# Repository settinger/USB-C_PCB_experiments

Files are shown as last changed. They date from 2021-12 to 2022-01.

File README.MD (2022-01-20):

# USB-C PCB Experiments

This is part of an ongoing series of projects involving creative interpretations of the USB mechanical standards. You've probably seen [2.0mm thick PCBs that fit in USB ports](http://digistump.com/products/1), and maybe you've seen [0.6mm thick PCBs that fit in USB-Micro cables](https://twitter.com/DHammarskjold/status/1285291152602796032). So what about USB-C? The plastic tab inside a USB-C port is about 0.7mm thick. I think [bobricius](https://hackaday.io/bobricius) has had success using 0.8mm thick PCBs; 0.6mm thick PCBs are way too loose. I haven't found a fab that will do 0.7mm (or 28 mil) PCBs unless you special-order an entire panel.

So, what other ways are there to reach 0.7mm thickness? My original plan was to join an 0.1mm flex PCB and an 0.6mm FR4 PCB, but then I realized: you know what else is 0.6mm thick? The ATtiny84A BGA package. Granted, there are only contacts on one side of the PCB, but that shouldn't matter with the symmetric USB-C pinout, right? ...Right? (foreshadowing)

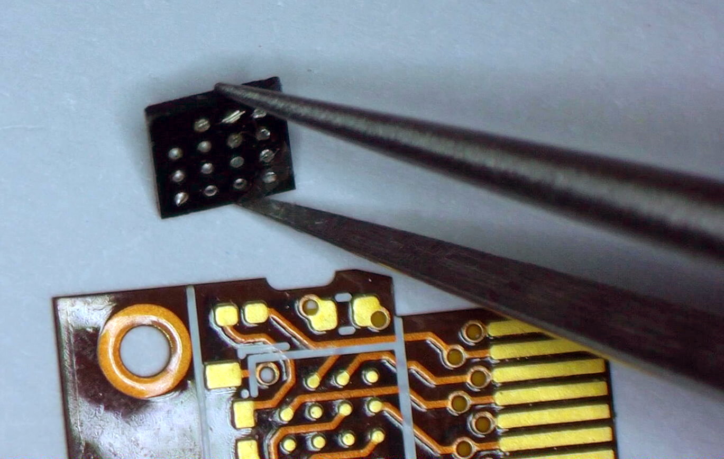
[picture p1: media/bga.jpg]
A close-up of the ATtiny84A in BGA package, next to a USB-C-shaped flex PCB


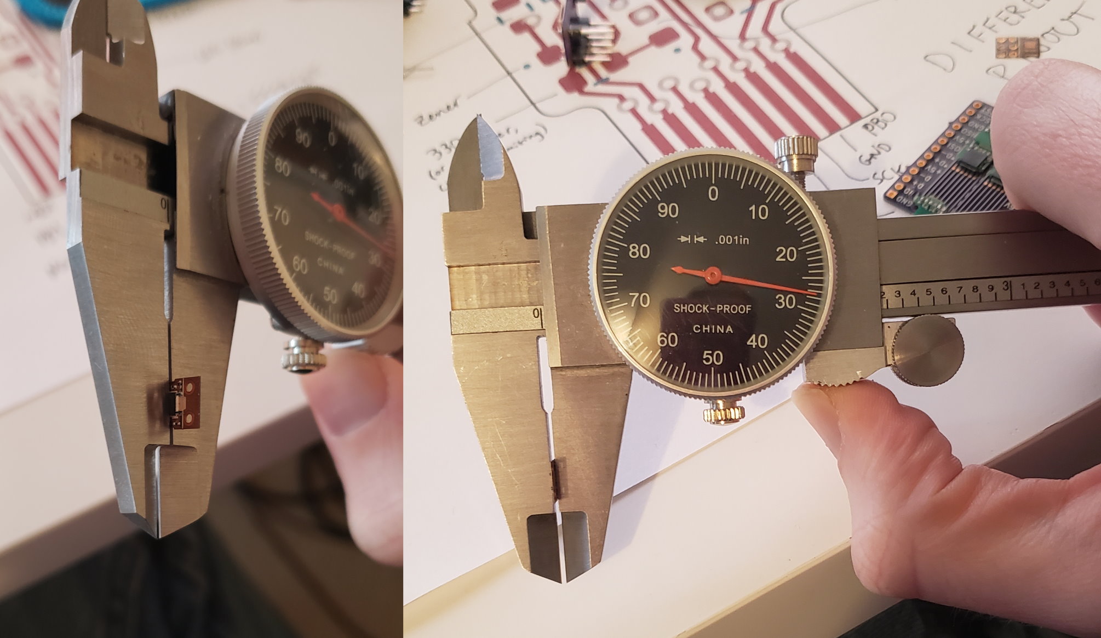
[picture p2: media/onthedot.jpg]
The BGA IC soldered onto the flex PCB, being measured by calipers that show 0.0275 inches (0.70 mm)


The 3mm-square ATtiny acts as a stiffener for the flex PCB, and it comes out to 0.7mm on the dot! I only have an imperial set of calipers as seen above. The dial shows 0.0275 inches, which is 0.6985 millimeters. ~~So this is looking pretty promising.~~ After [my initial tests](https://twitter.com/DHammarskjold/status/1476667605746270224), I am leaning toward a circuit sandwiched between two PCBs. The result is about 0.85mm thick with OSH Park flex PCBs, so I may need to locate another vendor.

What would you do with an ATtiny that lives inside your USB-C cable? I have a few ideas for demonstrations at the moment.

## Demo 1: RGB LED that can't be programmed over USB

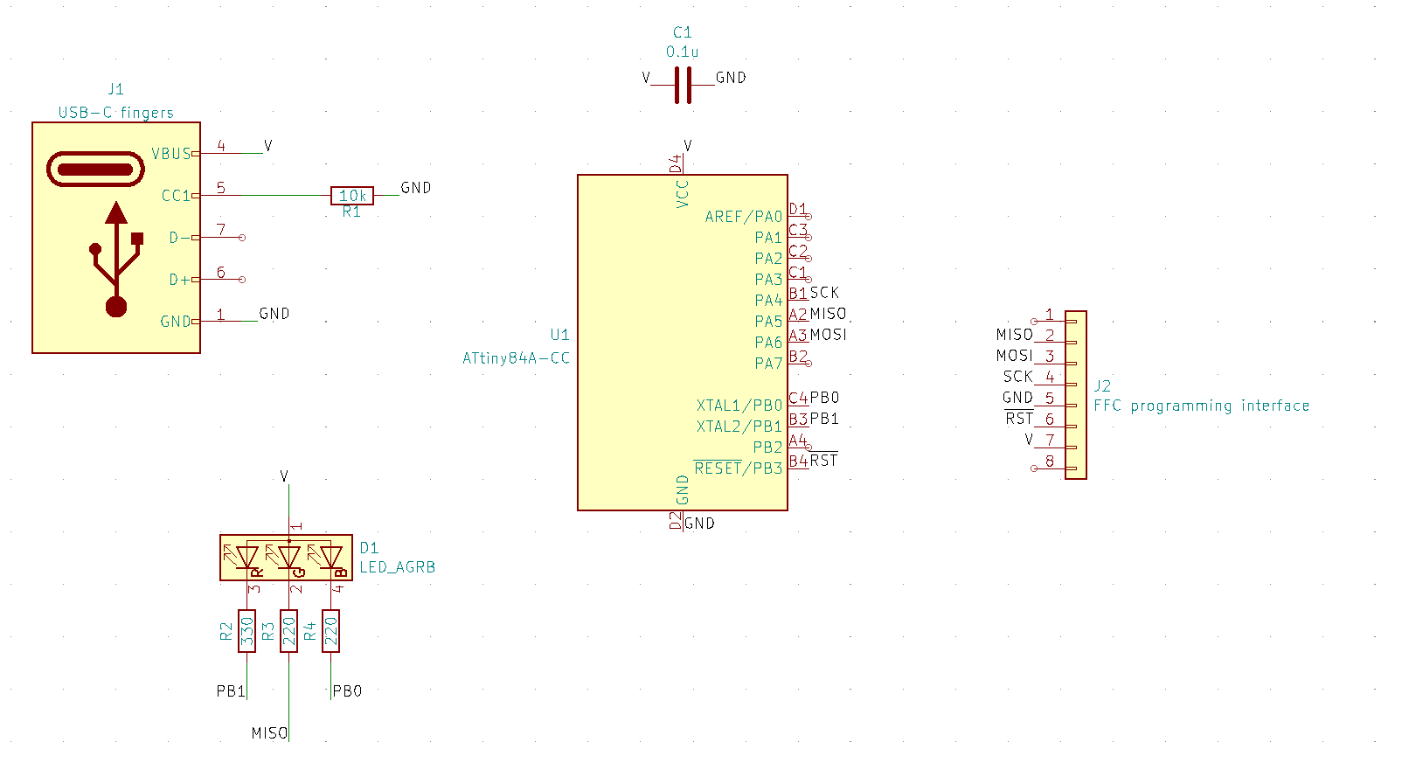
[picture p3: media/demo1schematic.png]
Schematic of revision 1 of the RGB LED USB-C PCB


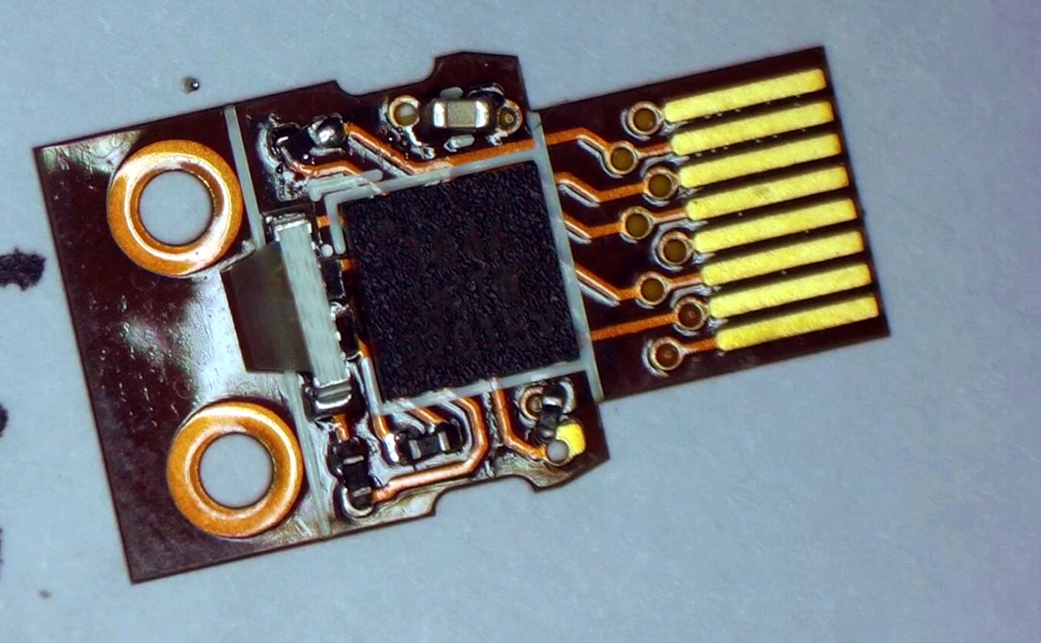
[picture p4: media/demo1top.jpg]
Top-down view of the assembled revision 1 PCB


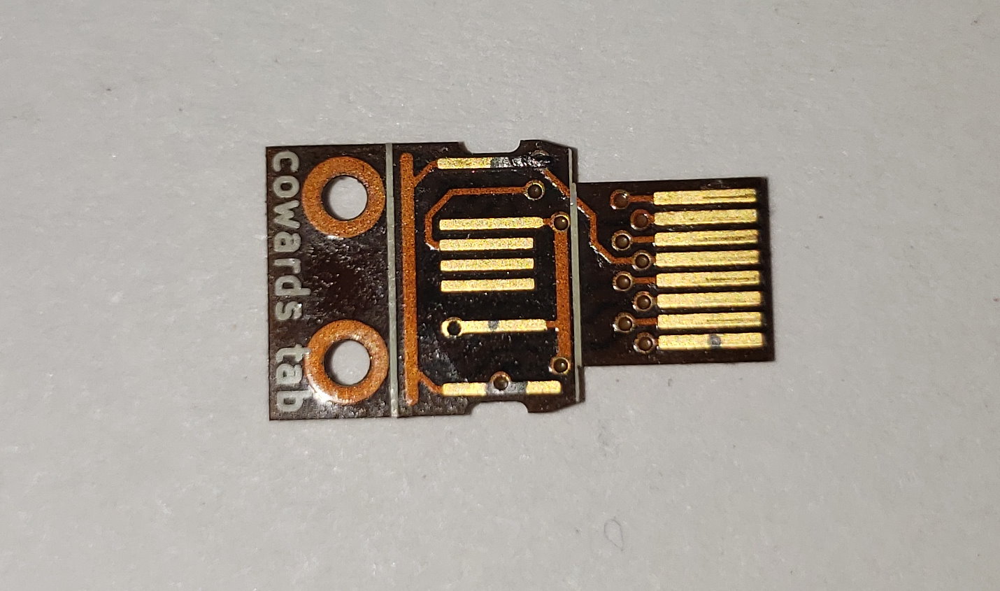
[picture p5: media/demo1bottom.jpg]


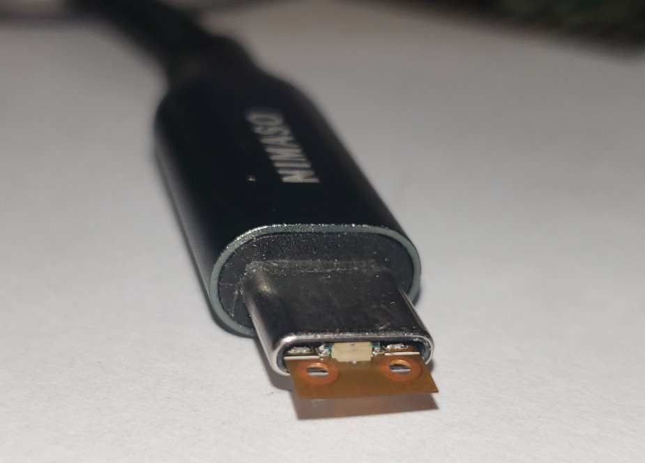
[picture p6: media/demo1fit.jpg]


There are two revisions of this design; the schematics are in the repo as `rgb_no_bootloader.kicad_sch` and `rgb_no_bootloader_r2.kicad_sch`. Revision 1 is the one that I have assembled and ready to work with, it's also the one I would like some code help with! My current code is in the in the code folder as `demo_1_revision_1`; it is saved as an Arduino .ino file but it should work fine with AVR-GCC without any changes.

This demo is as simple as possible: the microcontroller controlls an RGB LED that juuuust barely pokes out of the USB-C cable plug. It has to be programmed using that 8-pin FFC connector, and then the FFC connector has to be snipped off in order to use the dang thing. Right now I have one fully-soldered version of revision 1, ~~but I haven't cut the FFC connector yet because I would like some help improving the code.~~

Demo 1 Revision 2 is necessary because, on revision 1, the RGB LED is *not* connected to the Fast-PWM-enabled pins on the microcontroller. As a result I have to use [binary code modulation](http://www.batsocks.co.uk/readme/art_bcm_3.htm) to achieve any sort of brightness control. It's working alright, [as shown here](https://twitter.com/DHammarskjold/status/1475741148522049536), ~~but I'm not confident enough with the code to chop off the programming connector yet.~~

When I finally removed the connector, I documented it [in this Twitter thread](https://twitter.com/DHammarskjold/status/1476667605746270224). I got excited and tried putting it in a powered USB cable while the top side was exposed. Unsurprisingly, this caused some shorts and some damage! I soldered in a new RGB LED and applied conformal coating. The conformal coating helped for a little while, but got scraped away pretty quickly. This suggests to me that any future designs will need to be sandwiched between *two* PCBs.

As you can see, there is a large tab sticking out so I can grab and remove the PCB from the cable. However, out of spite for, uh, myself, I have labelled it the "cowards' tab." Past me was encouraging present me to remove that tab and make the board impossible to remove, thereby turning a useful cable into a cute little art piece for all eternity.

## Demo 2: ~~R~~GB LED that *can* be programmed over USB

It would be nice to use the USB data lines to program the microcontroller! I didn't attempt this for the first revision because I wanted to keep the board as uncluttered and simple as possible. It will result in a denser board that may need more careful soldering, but it should be possible! Well, *mostly* possible. I didn't find a way to route red green and blue at the same time, so I've omitted red from the design.

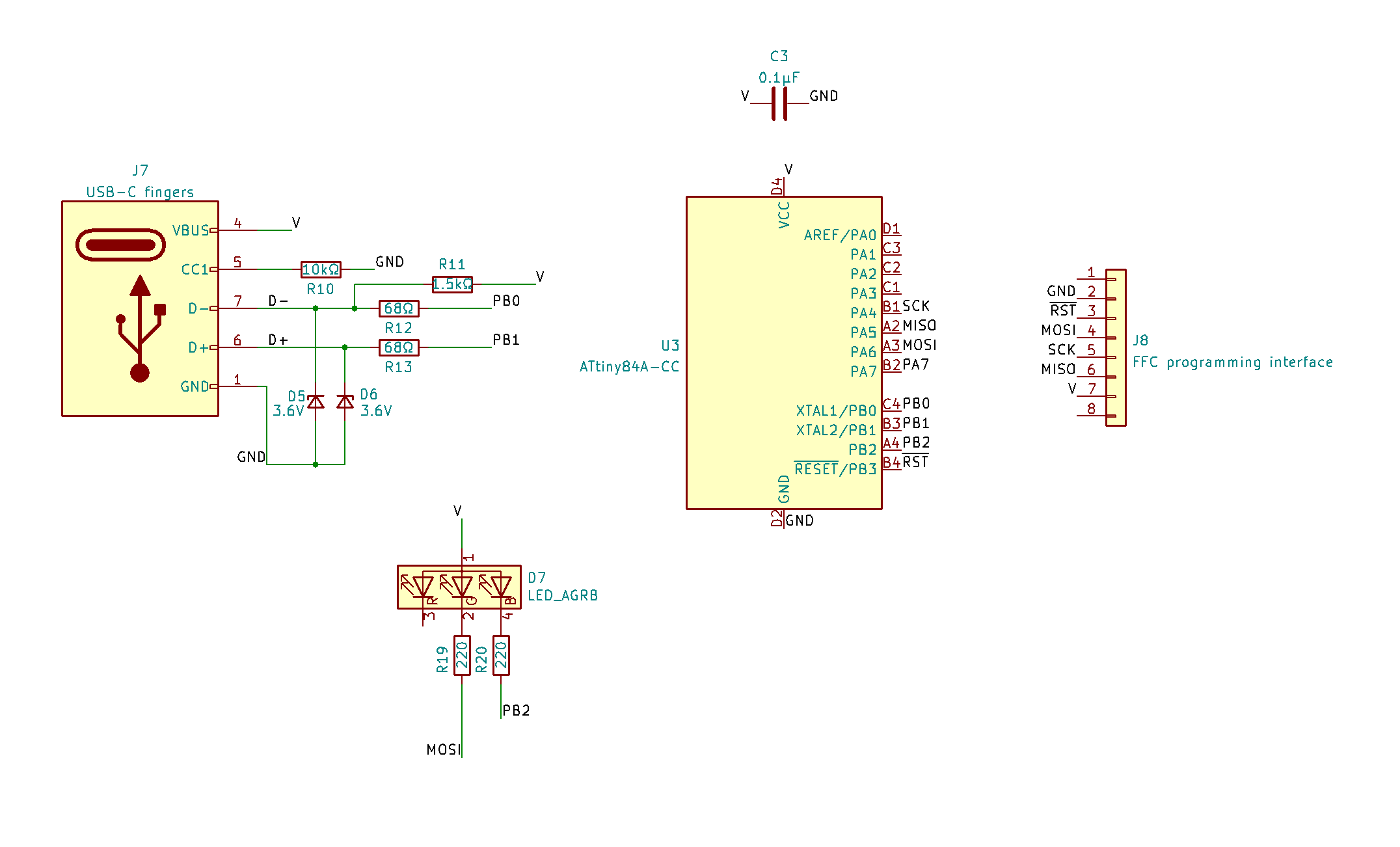
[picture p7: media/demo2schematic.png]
Schematic of the programmable RGB LED USB-C PCB


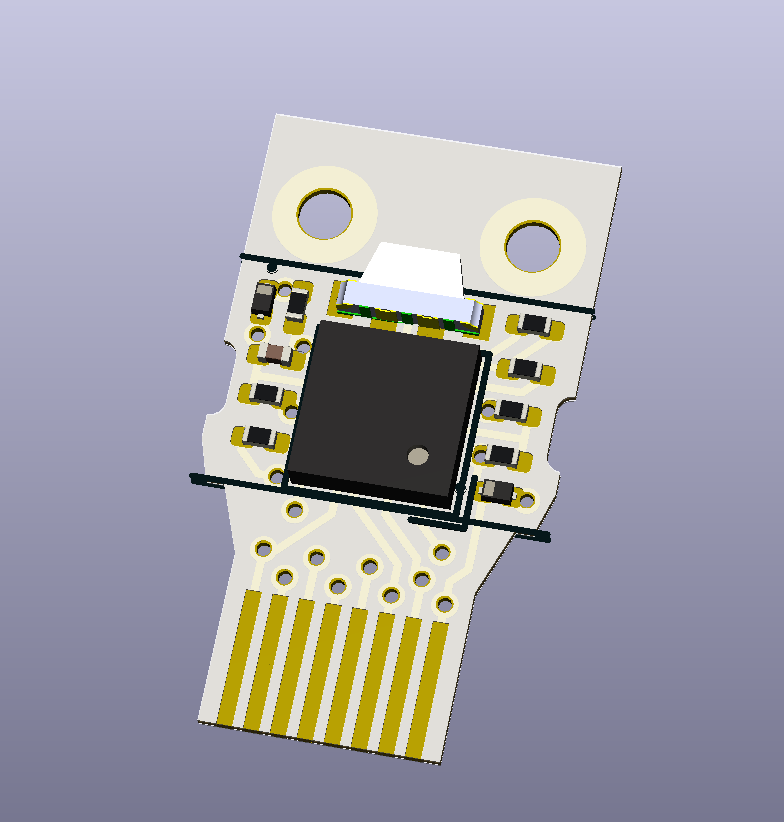
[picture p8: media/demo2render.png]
KiCad 3D render of the programmable RGB LED USB-C PCB


As I understand it, I need to add at least five extra components: a pullup for the D- line, small resistors on the D- and D+ lines, and zener diodes as level shifters. This is the low-complexity approach used on the Digispark and its derivatives. I have not attempted to make this board yet. Also, look at the 3d render above; doesn't it look like an owl? I love it.

There is an interesting issue, however. In the USB-C standard, the D+/D- lines are only connected on one side of the plug! It assumes that the USB-C port has D+/D- connectors on both sides, so the plug orientation should not matter. But our USB-C port only has D+/D- connectors on one side. We've reintroduced the classic USB behavior of having to flip the device over 3 times before it works!

## Demo 3: Basically a Digispark but smaller

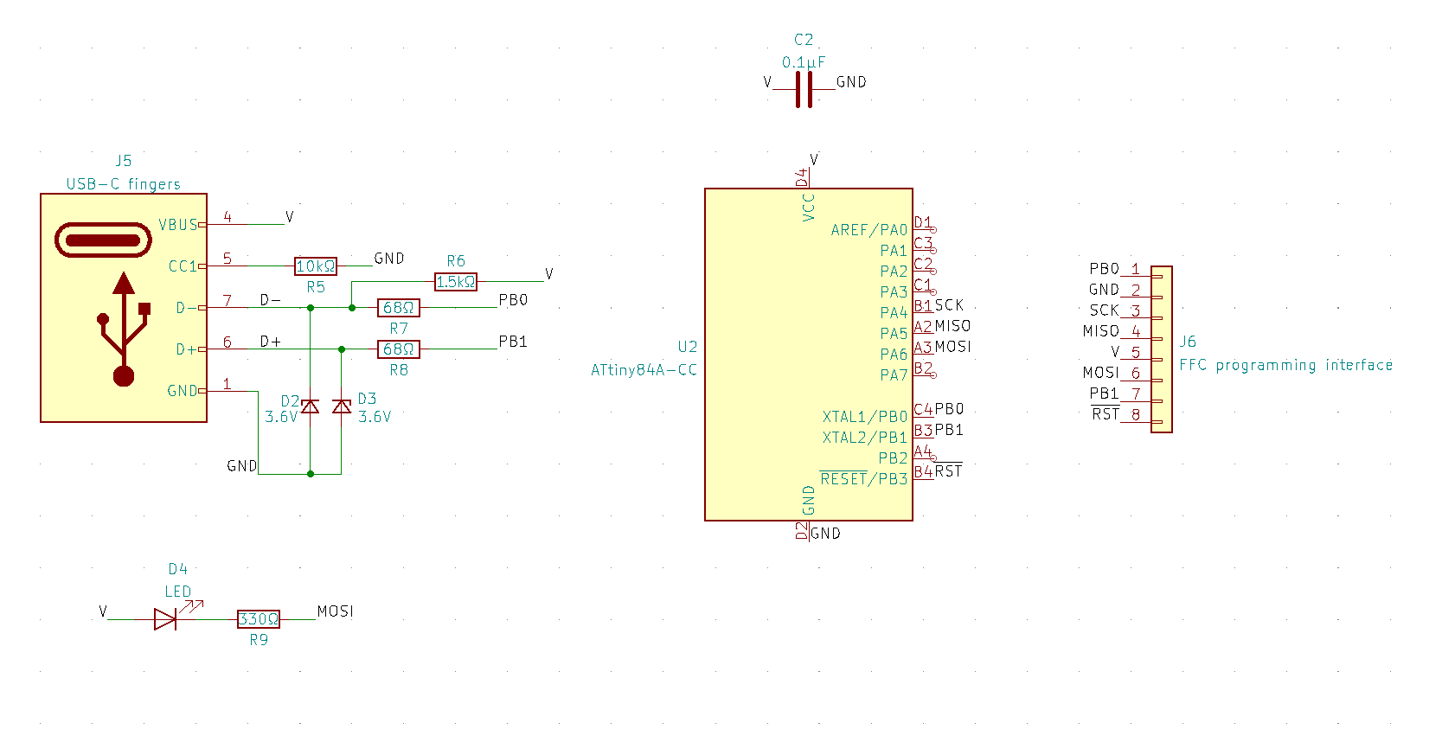
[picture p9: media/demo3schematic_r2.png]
Schematic of the miniature Digispark PCB


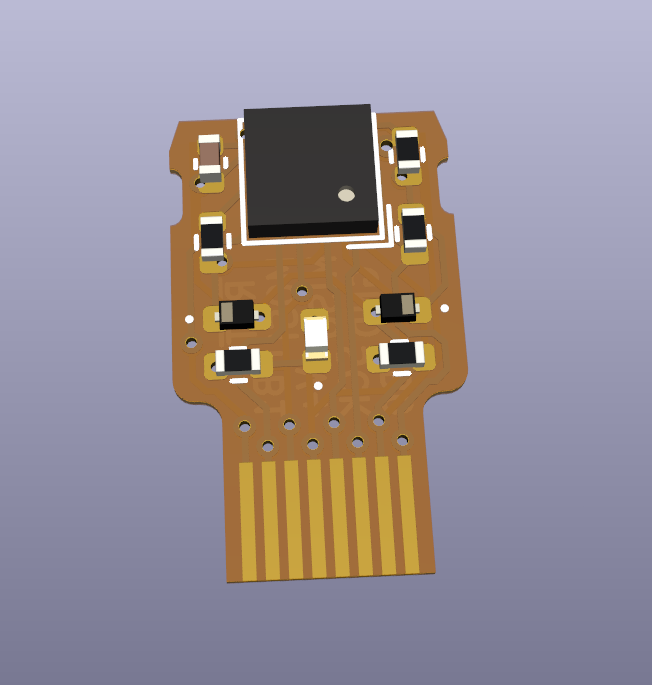
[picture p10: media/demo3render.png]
KiCad 3D render of the miniature Digispark PCB


In this version, the FFC portion is meant to stay attached! And all the components are 0402-sized with generous spacing so I can worry less when soldering. As a result it can be used in a slightly more "normal" fashion—still operable by sticking it inside a USB-C cable, but now there's a breakout of sorts.

## Demo 4: "Coulda used a 555"

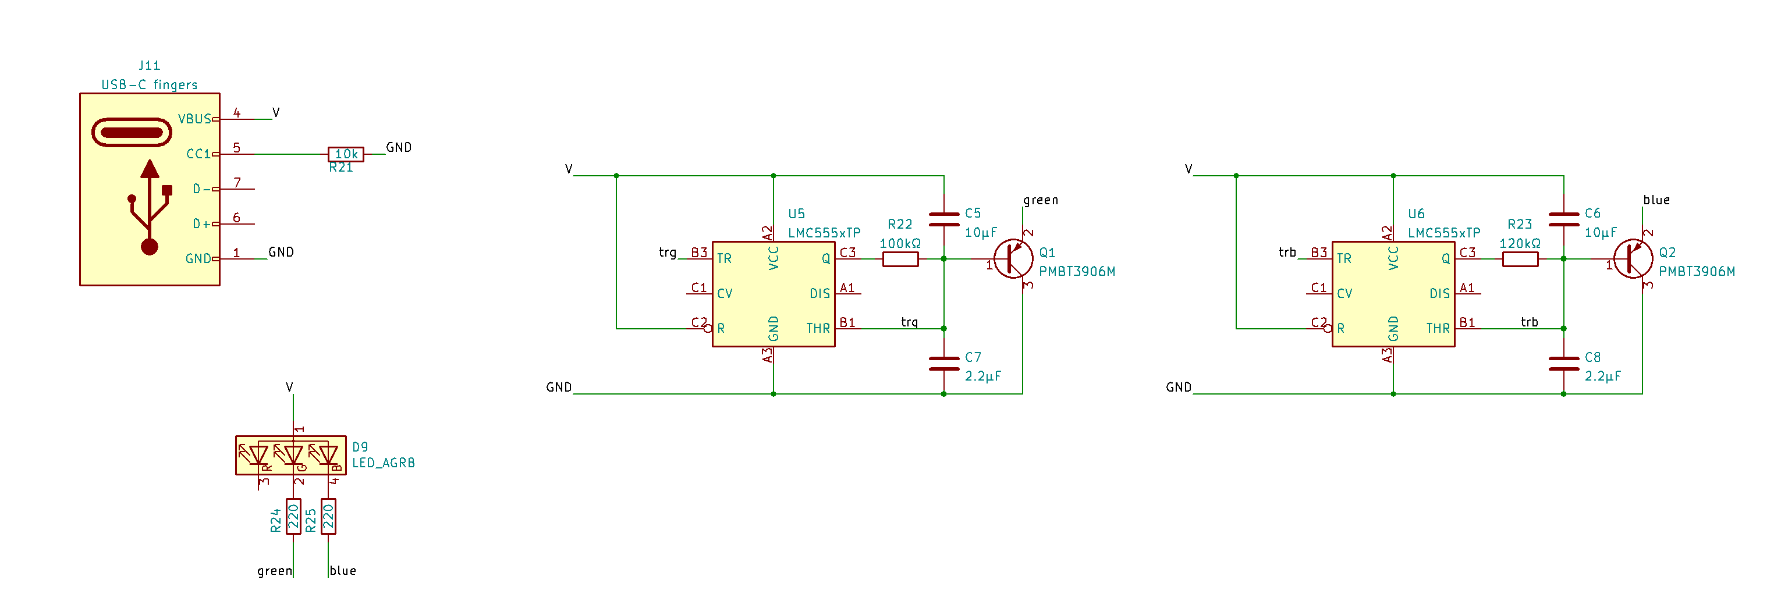
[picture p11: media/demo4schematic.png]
Schematic of the USB-C PCB using BGA 555 timers instead of a microcontroller


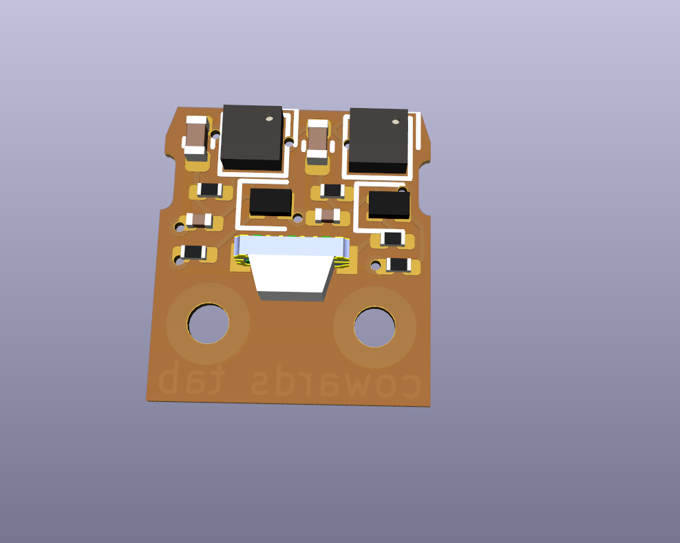
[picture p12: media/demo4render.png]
KiCad 3D render of the USB-C PCB using BGA 555 timers instead of a microcontroller


On the Hackaday websites, "Coulda used a 555" is shorthand for grumpy commenters who criticize designs that they consider inelegant, for example, using a microcontroller where a 555 would suffice. In the past I've poked fun at this notion by, among other things, using *three* microcontrollers where a 555 would suffice, and using a 555 Schmitt Trigger where a single SPST button would suffice. As luck would have it, there is a BGA 555 IC that is just shy of 0.6mm tall! I've had to pair it with a 10μF capacitor that is a bit taller, but it's a fun idea to explore later.

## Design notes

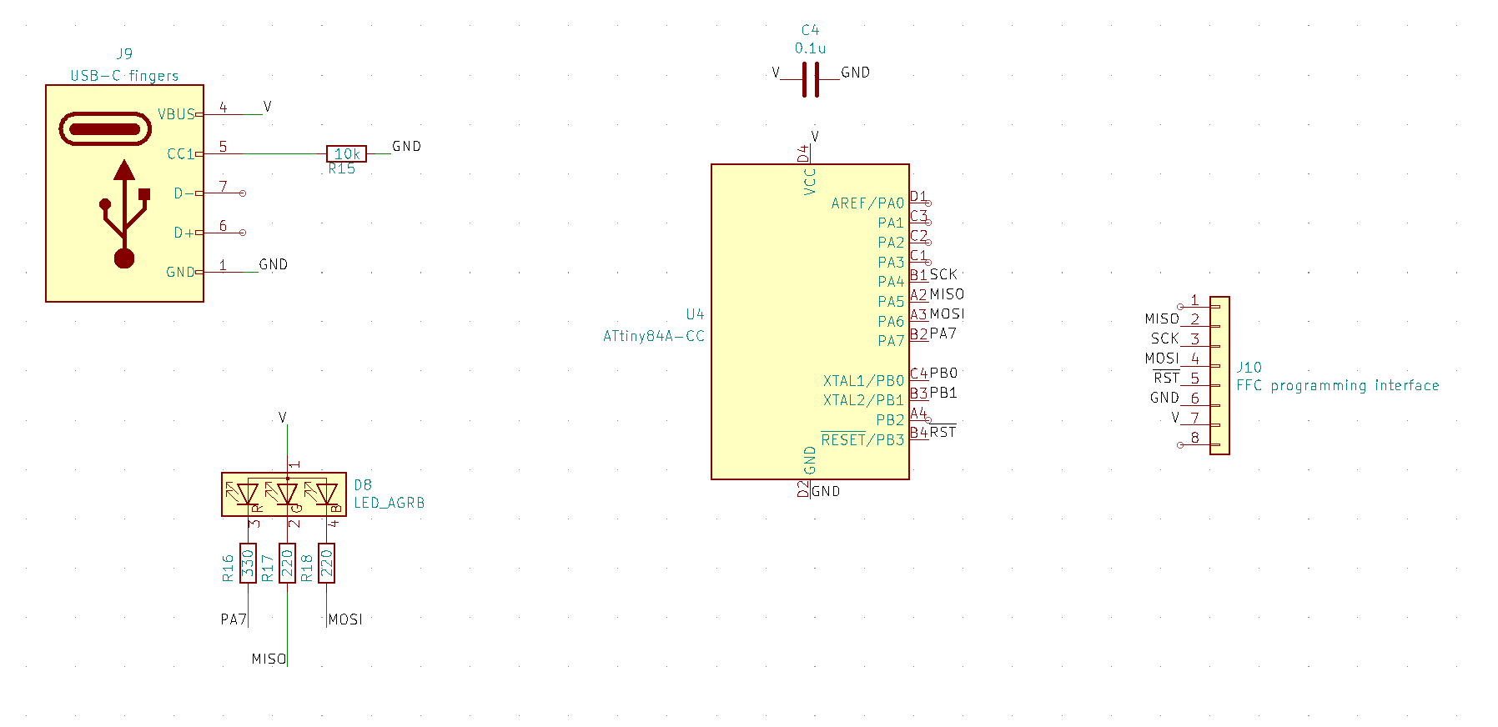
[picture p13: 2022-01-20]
media/demo1schematic_r2.png

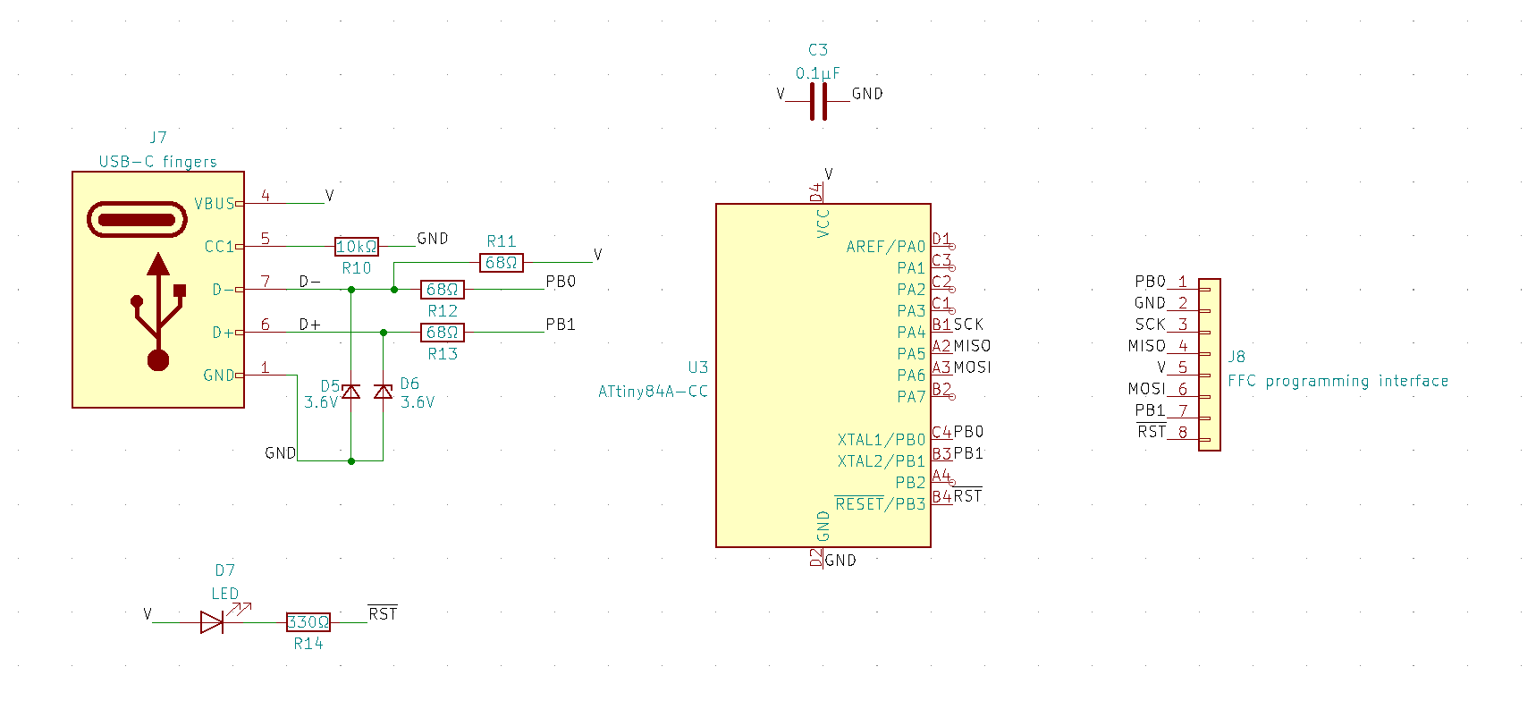
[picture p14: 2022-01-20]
media/demo3schematic.png

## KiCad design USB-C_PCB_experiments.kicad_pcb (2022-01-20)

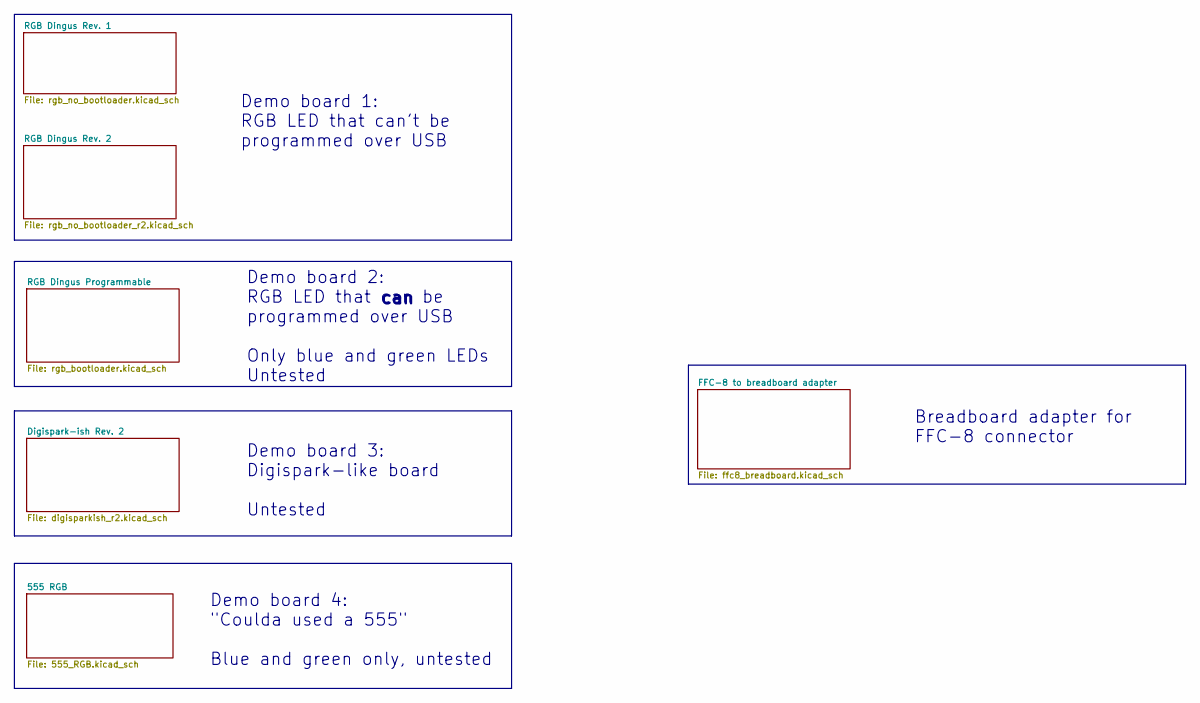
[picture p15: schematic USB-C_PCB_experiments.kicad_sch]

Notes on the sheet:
Breadboard adapter for FFC-8 connector
Demo board 1: RGB LED that can't be programmed over USB
Demo board 4: "Coulda used a 555" Blue and green only, untested
Demo board 3: Digispark-like board Untested
can
Demo board 2: RGB LED that can be programmed over USB Only blue and green LEDs Untested

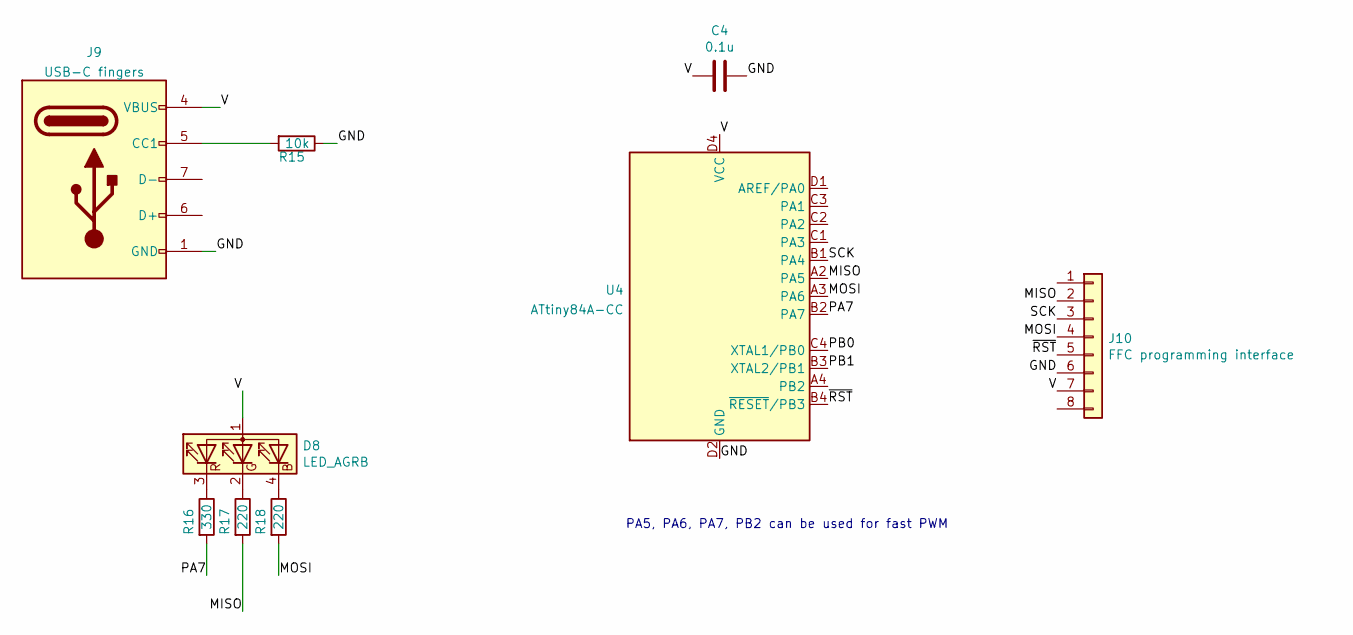
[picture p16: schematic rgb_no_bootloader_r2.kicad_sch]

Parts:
C4: 0.1u; C_0201_0603Metric
D8: LED_AGRB; LED_everlight_EASV2713RGBA1
J9: USB-C fingers
J10: FFC programming interface; FFC-08
R15: 10k; R_0201_0603Metric
R16: 330; R_0201_0603Metric
R17, R18: 220; R_0201_0603Metric
U4: ATtiny84A-CC; UFBGA-15_3.0x3.0mm_Layout4x4_P0.65mm

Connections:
/RGB Dingus Rev. 2/GND: C4.1, J9.1 (GND), J9.12 (GND), J10.6, R15.1, U4.D2 (GND), U4.D3 (GND)
/RGB Dingus Rev. 2/MISO: J10.2, R17.2, U4.A2 (PA5)
/RGB Dingus Rev. 2/MOSI: J10.4, R18.2, U4.A3 (PA6)
/RGB Dingus Rev. 2/PA7: R16.2, U4.B2 (PA7)
/RGB Dingus Rev. 2/PB0: U4.C4 (XTAL1/PB0)
/RGB Dingus Rev. 2/PB1: U4.B3 (XTAL2/PB1)
/RGB Dingus Rev. 2/SCK: J10.3, U4.B1 (PA4)
/RGB Dingus Rev. 2/V: C4.2, D8.1 (A), J9.4 (VBUS), J9.9 (VBUS), J10.7, U4.D4 (VCC)
/RGB Dingus Rev. 2/~RST: J10.5, U4.B4 (~RESET/PB3)
unnamed: D8.2 (GK), R17.1
unnamed: D8.3 (RK), R16.1
unnamed: D8.4 (BK), R18.1
unnamed: J9.5 (CC1), R15.2

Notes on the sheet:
PA5, PA6, PA7, PB2 can be used for fast PWM

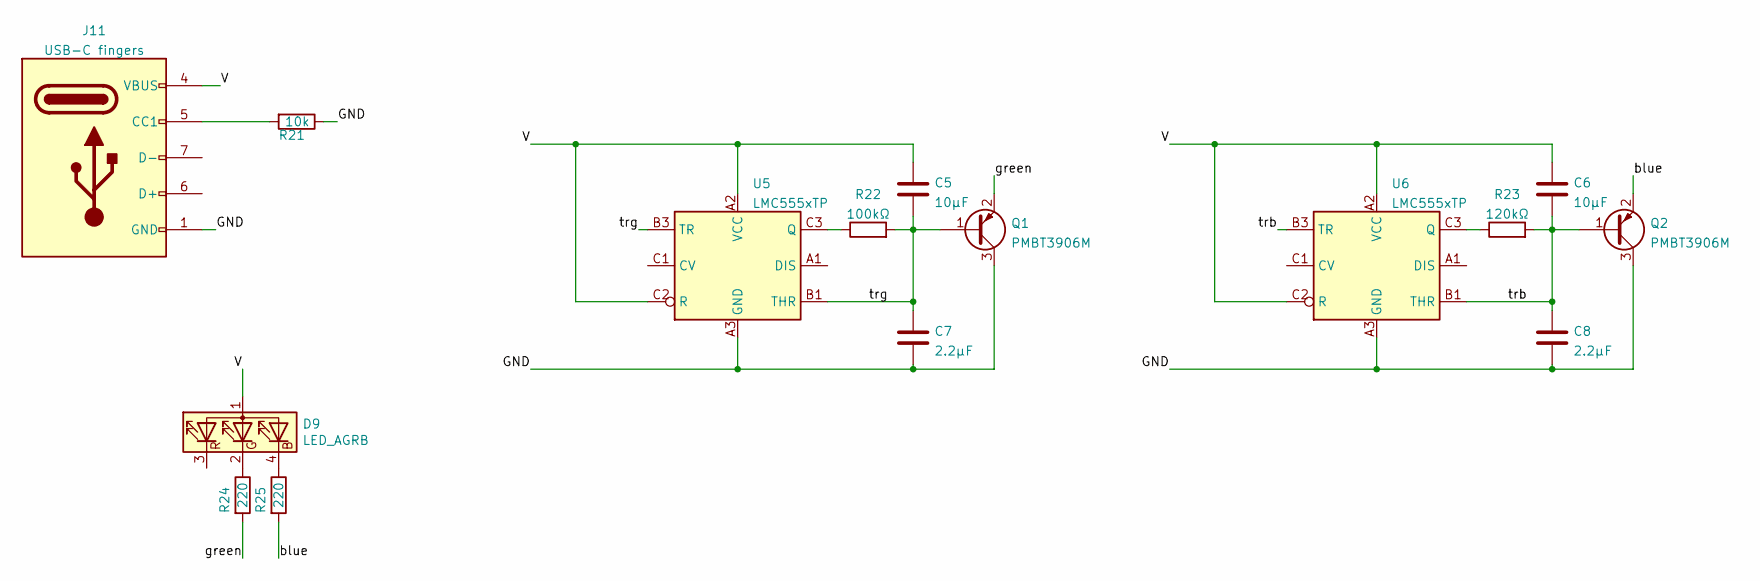
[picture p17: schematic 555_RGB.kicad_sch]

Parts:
C5, C6: 10μF; C_0402_1005Metric
C7, C8: 2.2μF; C_0201_0603Metric
D9: LED_AGRB; LED_everlight_EASV2713RGBA1
J11: USB-C fingers
Q1, Q2: PMBT3906M; SOT-883
R21: 10k; R_0201_0603Metric
R22: 100kΩ; R_0201_0603Metric
R23: 120kΩ; R_0201_0603Metric
R24, R25: 220; R_0201_0603Metric
U5, U6: LMC555xTP; Texas_DSBGA-8_1.43x1.41mm_Layout3x3_P0.5mm

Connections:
/555 RGB/GND: C7.2, C8.2, J11.1 (GND), J11.12 (GND), Q1.3 (C), Q2.3 (C), R21.1, U5.A3 (GND), U6.A3 (GND)
/555 RGB/V: C5.1, C6.1, D9.1 (A), J11.4 (VBUS), J11.9 (VBUS), U5.A2 (VCC), U5.C2 (R), U6.A2 (VCC), U6.C2 (R)
/555 RGB/blue: Q2.2 (E), R25.2
/555 RGB/green: Q1.2 (E), R24.2
/555 RGB/trb: C6.2, C8.1, Q2.1 (B), R23.2, U6.B1 (THR), U6.B3 (TR)
/555 RGB/trg: C5.2, C7.1, Q1.1 (B), R22.2, U5.B1 (THR), U5.B3 (TR)
unnamed: D9.2 (GK), R24.1
unnamed: D9.4 (BK), R25.1
unnamed: J11.5 (CC1), R21.2
unnamed: R22.1, U5.C3 (Q)
unnamed: R23.1, U6.C3 (Q)

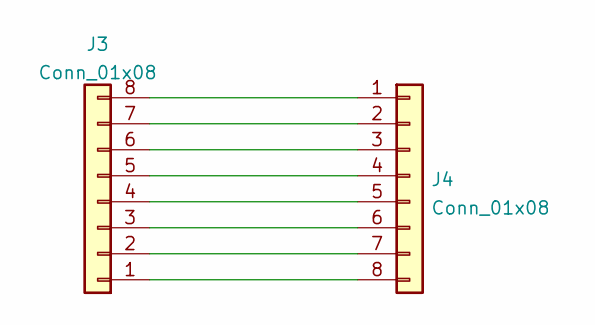
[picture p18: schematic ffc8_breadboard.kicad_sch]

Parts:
J3: Conn_01x08
J4: Conn_01x08; PinHeader_1x08_P2.54mm_Vertical

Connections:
unnamed: J3.1, J4.8
unnamed: J3.2, J4.7
unnamed: J3.3, J4.6
unnamed: J3.4, J4.5
unnamed: J3.5, J4.4
unnamed: J3.6, J4.3
unnamed: J3.7, J4.2
unnamed: J3.8, J4.1

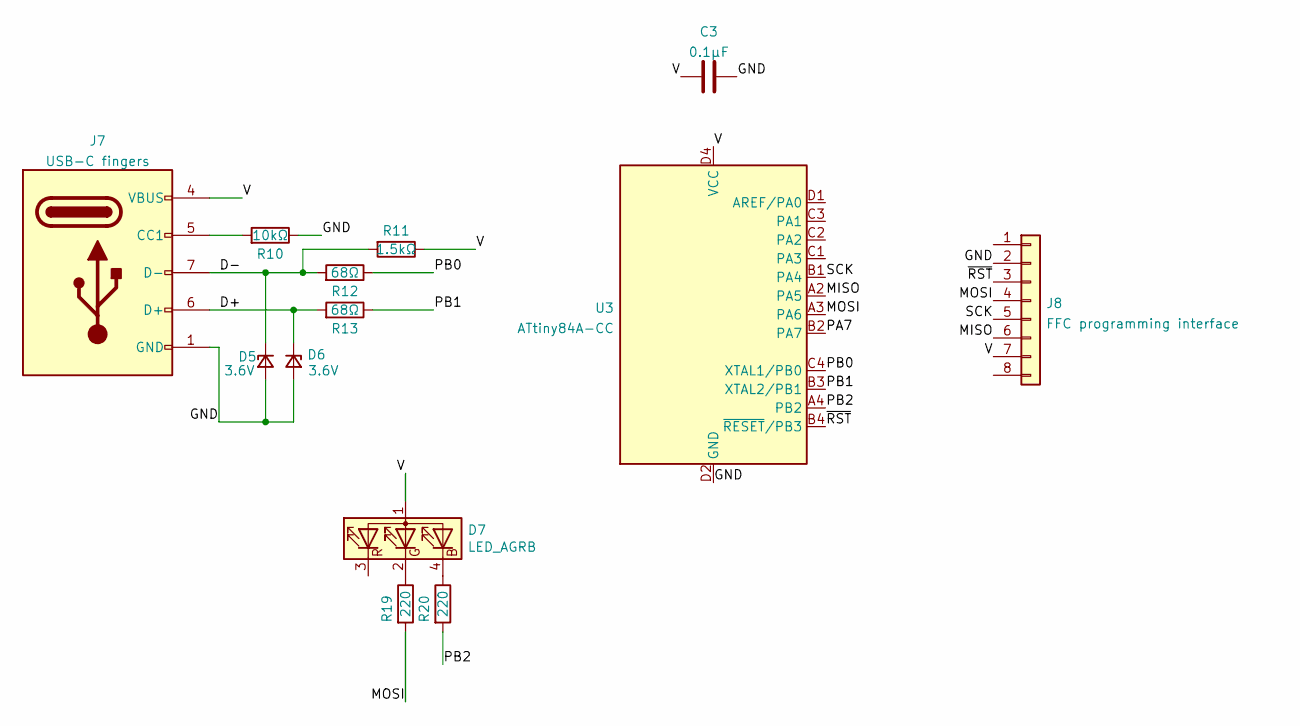
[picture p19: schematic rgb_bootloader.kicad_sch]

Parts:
C3: 0.1μF; C_0402_1005Metric
D5, D6: 3.6V; D_0402_1005Metric
D7: LED_AGRB; LED_everlight_EASV2713RGBA1
J7: USB-C fingers; usb-c-one-sided
J8: FFC programming interface; FFC-08
R10: 10kΩ; R_0402_1005Metric
R11: 1.5kΩ; R_0402_1005Metric
R12, R13: 68Ω; R_0402_1005Metric
R19, R20: 220; R_0201_0603Metric
U3: ATtiny84A-CC; UFBGA-15_3.0x3.0mm_Layout4x4_P0.65mm

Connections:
/RGB Dingus Programmable/D+: D6.1 (K), J7.6 (D+), R13.2
/RGB Dingus Programmable/D-: D5.1 (K), J7.7 (D-), R11.2, R12.2
/RGB Dingus Programmable/GND: C3.1, D5.2 (A), D6.2 (A), J7.1 (GND), J7.12 (GND), J8.2, R10.1, U3.D2 (GND), U3.D3 (GND)
/RGB Dingus Programmable/MISO: J8.6, U3.A2 (PA5)
/RGB Dingus Programmable/MOSI: J8.4, R19.2, U3.A3 (PA6)
/RGB Dingus Programmable/PA7: U3.B2 (PA7)
/RGB Dingus Programmable/PB0: R12.1, U3.C4 (XTAL1/PB0)
/RGB Dingus Programmable/PB1: R13.1, U3.B3 (XTAL2/PB1)
/RGB Dingus Programmable/PB2: R20.2, U3.A4 (PB2)
/RGB Dingus Programmable/SCK: J8.5, U3.B1 (PA4)
/RGB Dingus Programmable/V: C3.2, D7.1 (A), J7.4 (VBUS), J7.9 (VBUS), J8.7, R11.1, U3.D4 (VCC)
/RGB Dingus Programmable/~RST: J8.3, U3.B4 (~RESET/PB3)
unnamed: D7.2 (GK), R19.1
unnamed: D7.4 (BK), R20.1
unnamed: J7.5 (CC1), R10.2

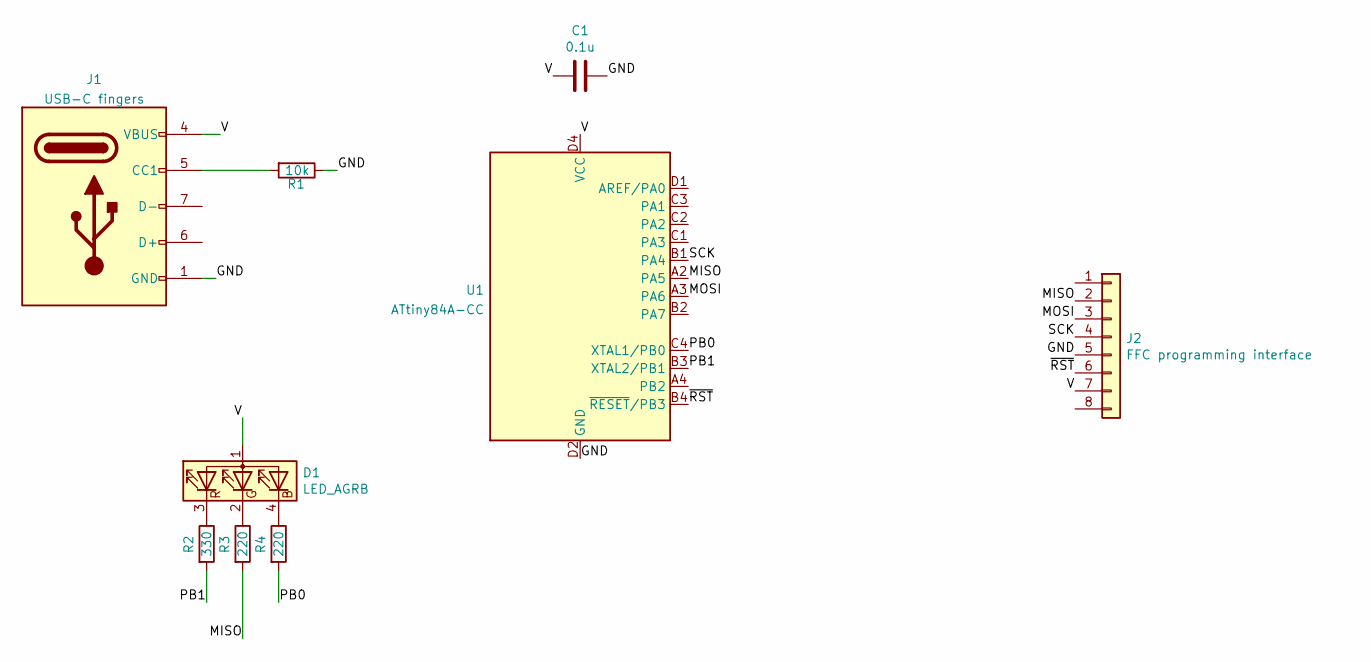
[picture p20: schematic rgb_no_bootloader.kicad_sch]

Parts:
C1: 0.1u; C_0201_0603Metric
D1: LED_AGRB; LED_everlight_EASV2713RGBA1
J1: USB-C fingers
J2: FFC programming interface; FFC-08
R1: 10k; R_0201_0603Metric
R2: 330; R_0201_0603Metric
R3, R4: 220; R_0201_0603Metric
U1: ATtiny84A-CC; UFBGA-15_3.0x3.0mm_Layout4x4_P0.65mm

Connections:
/RGB Dingus Rev. 1/GND: C1.1, J1.1 (GND), J1.12 (GND), J2.5, R1.1, U1.D2 (GND), U1.D3 (GND)
/RGB Dingus Rev. 1/MISO: J2.2, R3.2, U1.A2 (PA5)
/RGB Dingus Rev. 1/MOSI: J2.3, U1.A3 (PA6)
/RGB Dingus Rev. 1/PB0: R4.2, U1.C4 (XTAL1/PB0)
/RGB Dingus Rev. 1/PB1: R2.2, U1.B3 (XTAL2/PB1)
/RGB Dingus Rev. 1/SCK: J2.4, U1.B1 (PA4)
/RGB Dingus Rev. 1/V: C1.2, D1.1 (A), J1.4 (VBUS), J1.9 (VBUS), J2.7, U1.D4 (VCC)
/RGB Dingus Rev. 1/~RST: J2.6, U1.B4 (~RESET/PB3)
unnamed: D1.2 (GK), R3.1
unnamed: D1.3 (RK), R2.1
unnamed: D1.4 (BK), R4.1
unnamed: J1.5 (CC1), R1.2

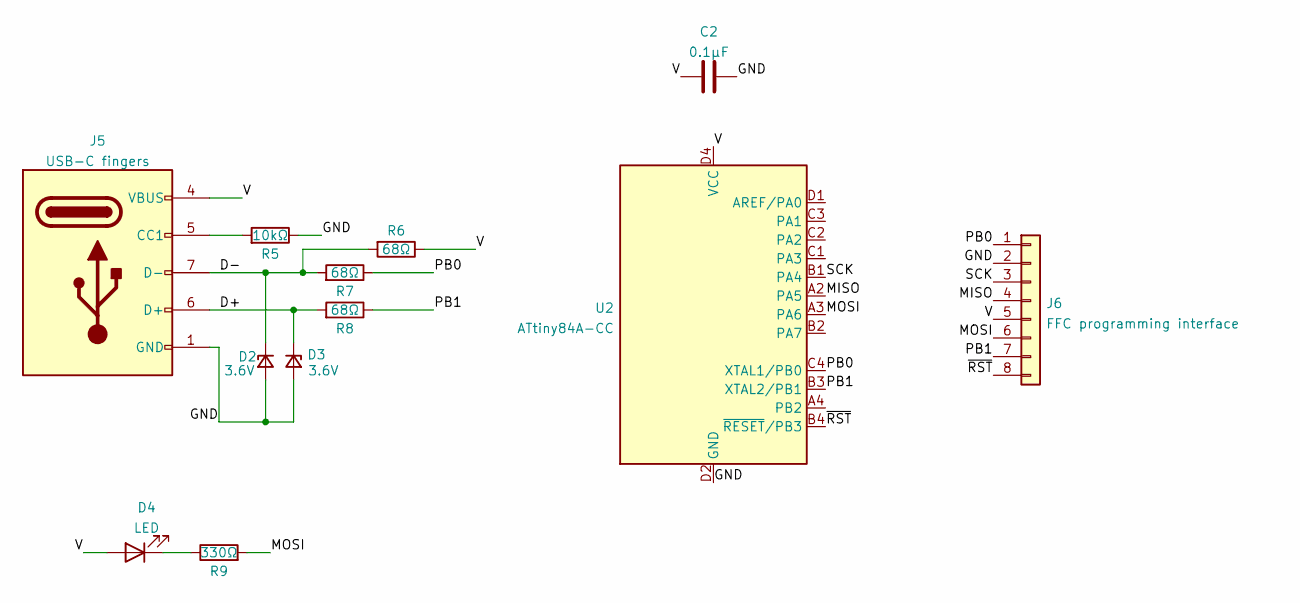
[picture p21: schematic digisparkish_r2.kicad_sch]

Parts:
C2: 0.1μF; C_0402_1005Metric
D2, D3: 3.6V; D_0402_1005Metric
D4: LED; LED_0402_1005Metric
J5: USB-C fingers; usb-c-one-sided
J6: FFC programming interface; FFC-08
R5: 10kΩ; R_0402_1005Metric
R6, R7, R8: 68Ω; R_0402_1005Metric
R9: 330Ω; R_0402_1005Metric
U2: ATtiny84A-CC; UFBGA-15_3.0x3.0mm_Layout4x4_P0.65mm

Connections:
/Digispark-ish Rev. 2/D+: D3.1 (K), J5.6 (D+), R8.2
/Digispark-ish Rev. 2/D-: D2.1 (K), J5.7 (D-), R6.2, R7.2
/Digispark-ish Rev. 2/GND: C2.1, D2.2 (A), D3.2 (A), J5.1 (GND), J5.12 (GND), J6.2, R5.1, U2.D2 (GND), U2.D3 (GND)
/Digispark-ish Rev. 2/MISO: J6.4, U2.A2 (PA5)
/Digispark-ish Rev. 2/MOSI: J6.6, R9.2, U2.A3 (PA6)
/Digispark-ish Rev. 2/PB0: J6.1, R7.1, U2.C4 (XTAL1/PB0)
/Digispark-ish Rev. 2/PB1: J6.7, R8.1, U2.B3 (XTAL2/PB1)
/Digispark-ish Rev. 2/SCK: J6.3, U2.B1 (PA4)
/Digispark-ish Rev. 2/V: C2.2, D4.2 (A), J5.4 (VBUS), J5.9 (VBUS), J6.5, R6.1, U2.D4 (VCC)
/Digispark-ish Rev. 2/~RST: J6.8, U2.B4 (~RESET/PB3)
unnamed: D4.1 (K), R9.1
unnamed: J5.5 (CC1), R5.2

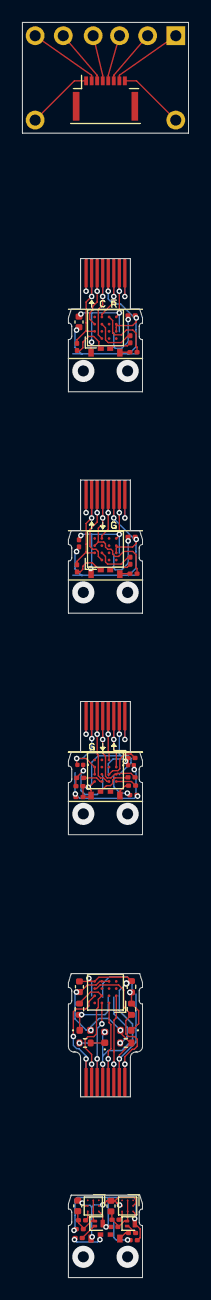
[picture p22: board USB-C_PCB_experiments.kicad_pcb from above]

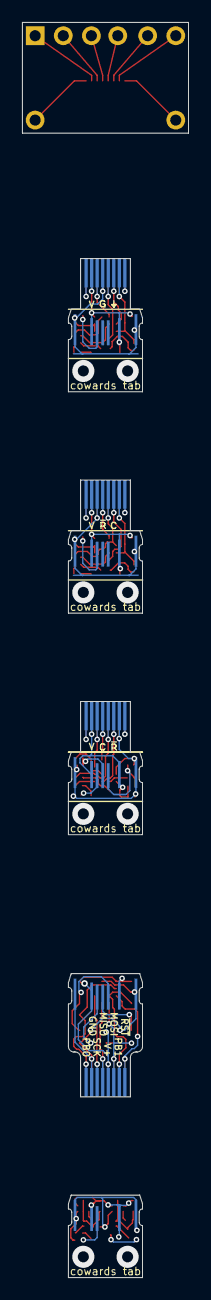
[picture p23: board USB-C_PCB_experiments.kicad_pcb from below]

Board: 2 copper layers, 15.0 x 113.4 mm, 60 parts (5 on the bottom side), 68 nets.

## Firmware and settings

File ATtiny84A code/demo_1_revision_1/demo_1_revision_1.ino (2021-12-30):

/* 
 * Okay dang I didn't read the ATtinycore very well and
 * I put my RGB LED signals on pins that don't have AnalogWrite()
 * functionality, so it's time for binary code modulation
 * for more info: http://www.batsocks.co.uk/readme/art_bcm_3.htm
 */

#include <avr/interrupt.h>

#define RED_PIN 9
#define GREEN_PIN 5
#define BLUE_PIN 10

volatile unsigned int frame = 6;
volatile unsigned char red = 10;
volatile signed int redDir = 1;
volatile unsigned char green = 0;
volatile signed int greenDir = 1;
volatile unsigned char blue = 70;
volatile signed int blueDir = 1;
volatile unsigned int cyclesToWait = 8191;

void setup() {
  CLKPR |= 1<<CLKPCE; // Enable Clock prescaler change
  CLKPR &= ~(15<<CLKPS0); // Clock prescaler changed to 1/1 (8 MHz) -- Must happen within 4 cycles of the last line
  
  // Timer/Counter 0 interrupts every 10 ms or so
  TCCR0A = 3<<WGM00;           // Fast PWM
  TCCR0B = 1<<WGM02 | 5<<CS00; // Fast PWM | 1:1024 prescaling, Page 84
  TIMSK0 = 1<<TOIE0;  // Timer Overflow Interrupt Enable
  OCR0A = 240; // Interrupt after 78 cycles (100 FPS ish)
  
  // Timer/Counter 1 interrupts after 4096 clock cycles, then 2048, then 1024, ...
  TCCR1A = 3<<WGM10;    // Fast PWM mode 15, page 110 // Try modes 11 or 9 maybe
  TCCR1B = 3<<WGM12 | 1<<CS10;    // Fast PWM mode 15 | No prescaling
  TIMSK1 = 1<<TOIE1;
  //OCR1A = 127; // Interrupt after 4096 cycles to start (approx 2 kHz) // Currently .5 khz?
  OCR1A = 2047;
  
  // Set port directions
  DDRB = 3<<DDB0;
  DDRA = 1<<DDA5;
  
  PORTB |= 1<<PORTB1;
  PORTA |= 1<<PORTA5;
  
  sei();
}

void loop() {
  
}

// on a Timer 1 overflow: WORKS NOW, FORGOT PRESCALER // Gets weirdly bright when jumping from 31 to 32 D:
ISR(TIM1_OVF_vect) {
  // Disable interrupts during this!
  unsigned char sreg;
  sreg = SREG; // Global interrupt flag
  cli(); // Disable interrupts
  cyclesToWait = OCR1A;
  if (blue & (1<<frame)) {
    PORTB &= ~(1<<PORTB0);
  } else {
    PORTB |= 1<<PORTB0;
  }
  if (red & (1<<frame)) {
    PORTB &= ~(1<<PORTB1);
  } else {
    PORTB |= 1<<PORTB1;
  }
  if (green & (1<<frame)) {
    PORTA &= ~(1<<PORTA5);
    } else {
    PORTA |= 1<<PORTA5;
  }
  if (frame <= 0) {
    cyclesToWait = 8191;
    frame = 6;
  } else {
    cyclesToWait = cyclesToWait>>1;
    frame--;
  }
  OCR1A = cyclesToWait;
  SREG = sreg; // Restore interrupts
}

// On a Timer 0 overflow: every 10 ms, update brightness (this works)
ISR(TIM0_OVF_vect) {
  // Disable interrupts??
  unsigned char sreg;
  sreg = SREG;
  cli();
  
  green += greenDir;
  if (green>=50) {
    green = 50;
    greenDir = -1;
    } else if (green <= 10) {
    green = 10;
    greenDir = 1;
  }
  
  red += redDir;
  if (red>=125) {
    red = 125;
    redDir = -1;
    } else if (red <= 10) {
    red = 10;
    redDir = 1;
  }
  
  blue += blueDir;
  if (blue>=110) {
    blue = 110;
    blueDir = -1;
  } else if (blue <= 0) {
    blue = 0;
    blueDir = 1;
  }
  
  SREG = sreg;
}

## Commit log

2021-12-30 Initial public release
    [USB-C_PCB_experiments.kicad_pcb, USB-C_PCB_experiments.kicad_sch, digisparkish_r2.kicad_sch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]
2022-01-20 Finished routing Demo 2, added Demo 4, updated readme with newer findings
    [555_RGB.kicad_sch, USB-C_PCB_experiments.kicad_pcb, USB-C_PCB_experiments.kicad_sch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]
